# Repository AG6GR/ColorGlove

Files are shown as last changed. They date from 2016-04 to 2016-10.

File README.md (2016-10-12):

# Palette

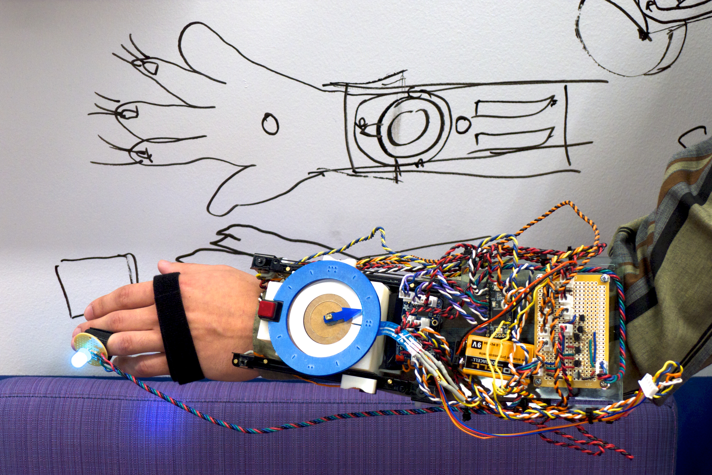
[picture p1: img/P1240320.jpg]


Palette was inspired by a desire to improve the way in which the visually impaired interact with color by creating a tool that would allow them to “feel” a tactile representation of color. Our device is used to translate color, a visual input, to tactile output and vice versa. However, our project also forced us to explore ways in which a user could intuitively interpret tactile information corresponding to color. The device functions as assistive technology or an artistic tool, allowing any user to translate between touch and color by “reading” color, which is translated into a physical representation, or by “setting” color on the device which is displayed on an LED on the device. While creating a prototype of our device, we worked to design a simple, elegant, and unobtrusive system for translating the representation of a spectrum of colors.

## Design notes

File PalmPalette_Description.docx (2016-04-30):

Noah Fishman, Nora Bradley, and Sunny He

STC 209

Final Project Description - Palm Palette

Palm Palette was inspired by a desire to improve the way in which the visually impaired interact with color by creating a tool that would allow them to “feel” a tactile representation of color. Our device is used to transform color, a visual input, to tactile output and vice versa. However, our project also forced us to explore ways in which a user could intuitively interpret tactile information corresponding to color. The device functions as assistive technology or an artistic tool, allowing any user to translate between touch and color by “reading” color, which is translated into a physical representation, or by “setting” color on the device which is displayed on an LED on the device. While this concept seemed simple at first, we found that the implementation of Pam Palette presented a number of interesting artistic and engineering challenges.

The first artistic challenge we faced was presented by the first moment of translation. How could we design a simple, elegant, and unobtrusive movement that translates into the more intangible and conceptual nature of color? In other words, how can color be physically represented in a way that is easy to understand, and that doesn’t necessarily rely on a concept of how people with sight experience color? The way we did this was to reduce color to a very small set of variables, a set of data that could provide all of the information we needed without being too overwhelming. We decided to use the Hue-Saturation-Value color model as a basis for our tactile color display. Hue maps directly well to a rotary dial, which helps to give the intuitive sensation that color is a spectrum. A stepper motor controlled a pointer on the dial to indicate the hue of a color being translated. We could label a few key colors like primary colors, and it would be fairly simple to understand the relation between colors based on their spatial distribution on the color wheel. Saturation and value are traditionally linear scales, and we ended up using motorized sliders to represent these parameters. Using simple sliders and dials, we strove for an interface that would make the translation feel seamless and easy to understand.

With that, we were left with another artistic consideration: How does representing color through another medium change the way that we can interact with it? To that end, how could these interactions be applied artistically? Eventually, we would hope to use the color glove device to control lighting in a theater or as a digital drawing tool, to ‘record’ the perception of color over time, and to even seek out colors in nature using the ‘set’ function of the apparatus. In this way, the device can redefine our perception of color, using the world as very tangible artistic palette.

The key engineering consideration influencing the design of Palm Palette was the need for the device to be portable. Early on, we realized that the device needed to be easy to move around and made a conscious effort to make Palm Palette as compact and wearable as possible. To this end, we took advantage of rapid prototyping techniques, working with 3D modeling software, 3D printers, and laser cutters to fabricate custom parts. We worked through many iterations of the block that mounted the dial and electronics to the user’s arm, playing with parameters such as curvature and size until we found a balance between stability and wearability. Palm Palette also entailed a fairly substantial amount of electronics and software. A Teensy microcontroller runs the various control loops interpreting color data from the color sensor and regulating the position of the dials and sliders. Many of these tools were new to us, and we were able to learn to use them with the help of course staff. Overall, the making of Palm Palette was a thoroughly exciting and instructive process that challenged us to use technology to approach the concept of color for a completely new artistic direction.

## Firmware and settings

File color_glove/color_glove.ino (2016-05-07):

#include <Wire.h>
#include <Stepper.h>
#include <SparkFun_APDS9960.h>

#define PIN_BUTTON 0
#define PIN_BUTTONGND 1

#define PIN_LED_RED 3
#define PIN_LED_GREEN 4
#define PIN_LED_BLUE 5

#define PIN_S_SLIDER_IN1 7
#define PIN_S_SLIDER_IN2 6
#define PIN_S_SLIDER_PWM 8
#define ADC_S_SLIDER 0

#define PIN_V_SLIDER_IN1 11
#define PIN_V_SLIDER_IN2 10
#define PIN_V_SLIDER_PWM 9
#define ADC_V_SLIDER 1

#define ADC_H_RING 2

// Color sensor I2C: SDA pin 18, SCL pin 19

#define STEPPER_STEPS 513
#define PIN_STEPPER_A1 20
#define PIN_STEPPER_A2 21
#define PIN_STEPPER_B1 22
#define PIN_STEPPER_B2 23

Stepper stepper = Stepper(STEPPER_STEPS, PIN_STEPPER_A1, PIN_STEPPER_A2,
    PIN_STEPPER_B1, PIN_STEPPER_B2); // Stepper motor object

// Deadband power level for sliders
#define MOTOR_DEADBAND 128

int stepperPosition = 0; // Position of the stepper (in steps)
int stepperTarget = 0; // Target position of the motor
int sensorValH = 0; // store the value coming from the sensor for H
int sensorValS = 0; // store the value coming from the sensor for S
int sensorValB = 0; // store the value coming from the sensor for B

// getRGB function stores RGB values in this array
// use these values for the red, blue, green led.
int rgb_colors[3];

int hue;
int saturation;
int brightness;

// Raw values from color sensor
SparkFun_APDS9960 apds = SparkFun_APDS9960();
uint16_t ambient_light = 0;
uint16_t red_light = 0;
uint16_t green_light = 0;
uint16_t blue_light = 0;

float slider_Kp = 0.5;
bool isActive = true;

void setup() {
    Wire.begin();
    Serial.begin(57600);

    // Button
    pinMode(PIN_BUTTON, INPUT_PULLUP);
    pinMode(PIN_BUTTONGND, OUTPUT);
    digitalWrite(PIN_BUTTONGND, LOW);

    // LED output pins
    pinMode(PIN_LED_RED, OUTPUT);
    pinMode(PIN_LED_GREEN, OUTPUT);
    pinMode(PIN_LED_BLUE, OUTPUT);
    analogWrite(PIN_LED_RED, 0);
    analogWrite(PIN_LED_GREEN, 0);
    analogWrite(PIN_LED_BLUE, 0);

    // Saturation slider pins
    pinMode(PIN_S_SLIDER_IN1, OUTPUT);
    pinMode(PIN_S_SLIDER_IN2, OUTPUT);
    pinMode(PIN_S_SLIDER_PWM, OUTPUT);
    digitalWrite(PIN_S_SLIDER_IN1, LOW);
    digitalWrite(PIN_S_SLIDER_IN2, LOW);
    analogWrite(PIN_S_SLIDER_PWM, 0);

    // Value slider pins
    pinMode(PIN_V_SLIDER_IN1, OUTPUT);
    pinMode(PIN_V_SLIDER_IN2, OUTPUT);
    pinMode(PIN_V_SLIDER_PWM, OUTPUT);
    digitalWrite(PIN_V_SLIDER_IN1, LOW);
    digitalWrite(PIN_V_SLIDER_IN2, LOW);
    analogWrite(PIN_V_SLIDER_PWM, 0);

    // Stepper setup
    stepper.setSpeed(60);

    // Initialize APDS-9960 (configure I2C and initial values)
    if ( apds.init() ) {
        Serial.println(F("APDS-9960 initialization complete"));
    } else {
        Serial.println(F("Something went wrong during APDS-9960 init!"));
    }

    // Start running the APDS-9960 light sensor (no interrupts)
    if ( apds.enableLightSensor(false) ) {
        Serial.println(F("Light sensor is now running"));
    } else {
        Serial.println(F("Something went wrong during light sensor init!"));
    }

    //Testing
    saturation = 128;
    brightness = 128;
    hue = 180;
}

void loop() {
    // Get HSV values
    sensorValH = analogRead(ADC_H_RING);
    sensorValS = analogRead(ADC_S_SLIDER);
    sensorValB = analogRead(ADC_V_SLIDER);

    //hue = (millis()/10) % 359;
    //saturation = (millis()/10) % 255;
    //brightness = (millis()/10) % 255;
    //Serial.println("Hue: " + String(sensorValH) + " Saturation: " + String(sensorValS) + " Brightness: " + String(sensorValB) + " isActive: " + String(isActive));

    // Get current mode from button
    if(digitalRead(PIN_BUTTON) == LOW)
    {
        isActive = false;
    }
    else
    {
        isActive = true;
    }

    if (isActive == true) // Actively display sensed color
    {
        // Get color from color sensor, save in hue,saturation,value variables
        if (  !apds.readAmbientLight(ambient_light) ||
            !apds.readRedLight(red_light) ||
        !apds.readGreenLight(green_light) ||
        !apds.readBlueLight(blue_light) )
        {
            Serial.println("Error reading light values");
        }
        else
        {
            /*
            Serial.print("Ambient: ");
            Serial.print(ambient_light);
            Serial.print(" Red: ");
            Serial.print(red_light);
            Serial.print(" Green: ");
            Serial.print(green_light);
            Serial.print(" Blue: ");
            Serial.println(blue_light);
            */

            RGBtoHSV(map(red_light, 0,ambient_light,0,255),
                map(green_light, 0,ambient_light,0,255),
                map(blue_light, 0,ambient_light,0,255));
            //Serial.println("Hue: " + String(hue) + " Saturation: " + String(saturation) + " Brightness: " + String(brightness));

            //brightness = 255;
        }

        // Set sliders
        setSlider(PIN_S_SLIDER_IN1, PIN_S_SLIDER_IN2, PIN_S_SLIDER_PWM,
            (int)((map(saturation, 0, 255, 0, 1023) - sensorValS) * slider_Kp));
        setSlider(PIN_V_SLIDER_IN1, PIN_V_SLIDER_IN2, PIN_V_SLIDER_PWM,
            (int)((map(brightness, 0, 255, 0, 1023) - sensorValB) * slider_Kp));

        // Set dial
        stepperTarget = map(hue, 0, 359, 0, STEPPER_STEPS);
        if (stepperPosition < stepperTarget)
        {
            stepper.step(min(3, stepperTarget - stepperPosition));
            stepperPosition += min(3, stepperTarget - stepperPosition);
        }
        else
        {
            stepper.step(max(-3, stepperTarget - stepperPosition));
            stepperPosition += max(-3, stepperTarget - stepperPosition);
        }
        saturation = 255;


    }
    else // Let user set color
    {

        if (sensorValH > 400)
        {
            hue = map(sensorValH, 400, 1024, 0, 360);
        }
        saturation = map(sensorValS, 0, 1024, 0, 255);
        brightness = map(sensorValB, 0, 1024, 0, 255);
        Serial.println("Hue: " + String(hue) + " Saturation: " + String(saturation) + " Brightness: " + String(brightness));

        // Disable slider motors
        setSlider(PIN_S_SLIDER_IN1, PIN_S_SLIDER_IN2, PIN_S_SLIDER_PWM, 0);
        setSlider(PIN_V_SLIDER_IN1, PIN_V_SLIDER_IN2, PIN_V_SLIDER_PWM, 0);
    }

    // Set color of leds
    HSVtoRGB(hue, brightness, saturation);
    analogWrite(PIN_LED_RED, 255 - rgb_colors[0]);
    analogWrite(PIN_LED_GREEN, 255 - rgb_colors[1]);
    analogWrite(PIN_LED_BLUE, 255 - rgb_colors[2]);
}

/*
* Set a motor to a given output value between 0 and 100. Positive values indicate
* forward direction, negative values indicate backward direction.
*/
void setSlider(int pin_1, int pin_2, int pin_pwm, int value)
{
    int pwmlevel = abs(value);
    //Serial.println("Setting: " + String(pin_1) + "," + String(pin_2) + "," + String(value));
    // Set controller direction
    if (pwmlevel < 2)
    {
        // Disengage if pwmlevel is very small
        pwmlevel = 0;
        digitalWrite(pin_1, LOW);
        digitalWrite(pin_2, LOW);
        analogWrite(pin_pwm, 0);
        return;
    }
    else if (value < 0)
    {
        // Backward
        digitalWrite(pin_2, LOW);
        digitalWrite(pin_1, HIGH);
    }
    else
    {
        // Forward
        digitalWrite(pin_1, LOW);
        digitalWrite(pin_2, HIGH);
    }

    // Check bounds on pwmlevel
    if (pwmlevel > 100)
    {
        pwmlevel = 100;
        analogWrite(pin_pwm, 255);
    }
    else
    {
        // Write new PWM value
        analogWrite(pin_pwm, map(pwmlevel, 0, 100, MOTOR_DEADBAND, 255));
    }
}

// Color conversion code from https://www.cs.rit.edu/~ncs/color/t_convert.html#RGB to HSV & HSV to RGB

void HSVtoRGB(int h_val, int s_val, int v_val)
{
    int i;
	float h,s,v,f, p, q, t, r, g, b;
	h = (float) h_val;
	s = (float) s_val / 255.0;
	v = (float) v_val / 255.0;
	if( s == 0 ) {
		// achromatic (grey)
		r = g = b = v;
		return;
	}
	h /= 60;			// sector 0 to 5
	i = floor( h );
	f = h - i;			// factorial part of h
	p = v * ( 1 - s );
	q = v * ( 1 - s * f );
	t = v * ( 1 - s * ( 1 - f ) );
	switch( i ) {
	case 0:
	    r = v;
	    g = t;
	    b = p;
	    break;
	case 1:
	    r = q;
	    g = v;
	    b = p;
	    break;
	case 2:
	    r = p;
	    g = v;
	    b = t;
	    break;
	case 3:
	    r = p;
	    g = q;
	    b = v;
	    break;
	case 4:
	    r = t;
	    g = p;
	    b = v;
	    break;
	default:		// case 5:
	    r = v;
	    g = p;
	    b = q;
	    break;
	}
	rgb_colors[0] = (int)(255 * r);
	rgb_colors[1] = (int)(255 * g);
	rgb_colors[2] = (int)(255 * b);
}

void RGBtoHSV(int r_val, int g_val, int b_val)
{
	float r,g,b,h,s,v;
    float min, max, delta;

    r = r_val / 255.0;
    g = g_val / 255.0;
    b = b_val / 255.0;

	min = min(min(r, g), b);
	max = max(max(r, g), b);
	v = max;				// v
	brightness = (int) (v * 255);
	delta = max - min;
	if( max != 0 )
		s = delta / max;		// s
	else {
		// r = g = b = 0		// s = 0, v is undefined
		saturation = 0;
		hue = 0;
		return;
	}
	if( r == max )
		h = ( g - b ) / delta;		// between yellow & magenta
	else if( g == max )
		h = 2 + ( b - r ) / delta;	// between cyan & yellow
	else
		h = 4 + ( r - g ) / delta;	// between magenta & cyan
	h *= 60;				// degrees
    h += 180;
	if( h < 0 )
		h += 360;
	hue = ((int)h) % 360;
	saturation = (int) (s * 255);
}

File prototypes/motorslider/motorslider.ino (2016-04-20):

#define PIN_MOTORA1 7
#define PIN_MOTORA2 8
#define PIN_MOTORAPWM 9
#define ADC_SLIDER_IN 0
#define MOTOR_DEADBAND 128

int sliderVal = 0;
int setpoint = 512;
float slider_Kp = 0.5;

void setup() {
  pinMode(PIN_MOTORA1, OUTPUT);
  pinMode(PIN_MOTORA2, OUTPUT);
  pinMode(PIN_MOTORAPWM, OUTPUT);

  digitalWrite(PIN_MOTORA1, LOW);
  digitalWrite(PIN_MOTORA2, LOW);
  analogWrite(PIN_MOTORAPWM, 0);

  Serial.begin(57600);
}

void loop() {
  // put your main code here, to run repeatedly:
  sliderVal = analogRead(0);
  Serial.println("Target: " + String(setpoint) + " Current: " + String(sliderVal));

  setMotor((int) ((setpoint - sliderVal) * slider_Kp));

  setpoint = (int) millis()/5 % 1000 + 5;
}

/*
 * Set a motor to a given output value between 0 and 100. Positive values indicate
 * forward direction, negative values indicate backward direction.
 */
void setMotor(int value)
{
  //Serial.println("Setting Value: " + String(value));
  int pwmlevel = abs(value);
  // Set controller direction
  if (pwmlevel < 1)
  {
    // Disengage if pwmlevel is very small
    pwmlevel = 0;
    digitalWrite(PIN_MOTORA1, LOW);
    digitalWrite(PIN_MOTORA2, LOW);
    analogWrite(PIN_MOTORAPWM, 0);
    return;
  }
  else if (value < 0)
  {
    // Backward
    digitalWrite(PIN_MOTORA2, LOW);
    digitalWrite(PIN_MOTORA1, HIGH);
  }
  else
  {
    // Forward
    digitalWrite(PIN_MOTORA1, LOW);
    digitalWrite(PIN_MOTORA2, HIGH);
  }

  // Check bounds on pwmlevel
  if (pwmlevel > 100)
  {
    pwmlevel = 100;
    analogWrite(PIN_MOTORAPWM, 255);
  }
  else
  {
    // Write new PWM value
    analogWrite(PIN_MOTORAPWM, map(pwmlevel, 0, 100, MOTOR_DEADBAND, 255));
  }
}

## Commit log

2016-04-27 Final version
    [TeensyPins.csv]
2016-05-07 Updated gitignore, touched up layout
    [LEDBoard.fzz]
2016-05-07 Moved prototype code
2017-03-30 Added updated colors
    [TeensyPins.csv]
